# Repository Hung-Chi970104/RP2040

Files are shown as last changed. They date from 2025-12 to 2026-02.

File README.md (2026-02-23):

# RP2040 Hacker Board
- Demo video (with radio nrf24l01): https://youtu.be/eCMlnlmFBuc
- Demo video (radio control nrf24l01): https://youtu.be/_LA9TkBpY54

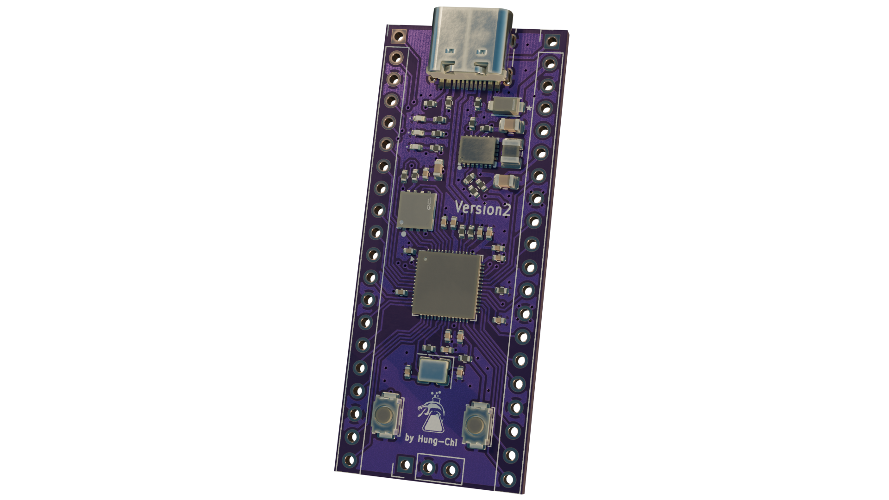
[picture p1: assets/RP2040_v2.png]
RP2040 V2


- Upgraded flash storage from 2MB (W25Q16JVUXIQ TR) to 16MB (W25Q64JVXGIQ)
- Replaced MCP1700x-330xxTT (linear regulator) with RT6154AGQW (buck-boost switching regulator)
- Added Schottky Diode to allow external power supply
- Added a RESET button
- Changed 33pF crystal cap to 15pF to match the crystal I ordered

## Components
- RP2040
- 12MHz Crystal (ABM8-272-T3)
- 8MB Flash Storage (W25Q64JVXGIQ)
- Buck-Boost Switching Regulator (RT6154AGQW)
- USB-C (TYPE-C-31-M-12)

## Pinouts
| Pin Number (Left) | Description | Pin Number (Right) | Description |
| --- | --- | --- | --- |
| 1 | GPIO0 | 1 | VBUS |
| 2 | GPIO1 | 2 | VSYS |
| 3 | GND | 3 | GND |
| 4 | GPIO2 | 4 | GPIO28_ADC2 |
| 5 | GPIO3 | 5 | GPIO27_ADC1 |
| 6 | GPIO4 | 6 | 3V3 |
| 7 | GPIO5 | 7 | GPIO26_ADC0 |
| 8 | BOOTSEL | 8 | GND |
| 9 | GPIO6 | 9 | GPIO25 |
| 10 | GPIO7 | 10 | GPIO24 |
| 11 | GPIO8 | 11 | GPIO23 |
| 12 | GPIO9 | 12 | GPIO22 |
| 13 | GND | 13 | GND |
| 14 | GPIO10 | 14 | GPIO21 |
| 15 | GPIO11 | 15 | GPIO20 |
| 16 | GPIO12 | 16 | GPIO19 |
| 17 | GPIO13 | 17 | GND |
| 18 | GND | 18 | GPIO18 |
| 19 | GPIO14 | 19 | GPIO17 |
| 20 | GPIO15 | 20 | GPIO16 |

## PCBs

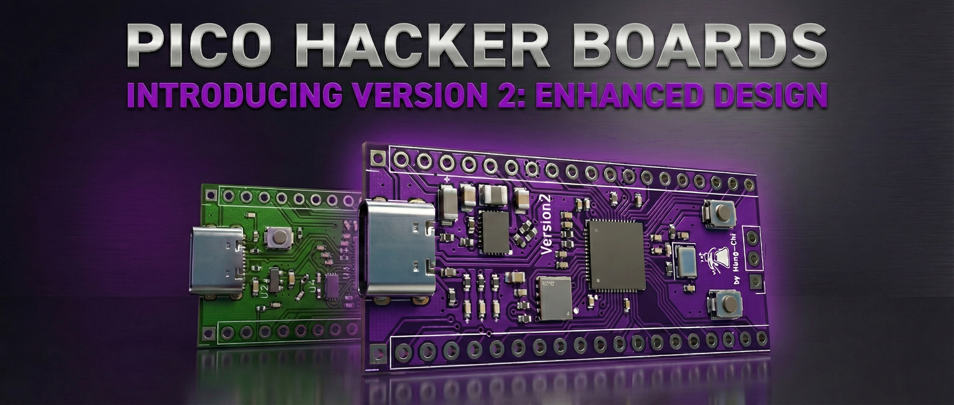
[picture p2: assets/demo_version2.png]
comparison


- 2 layers
- Single-sided component placement
- 2.6mm board thickness
- HASL (with lead) surface finish
- 1oz outer copper weight

### PCB Schematic
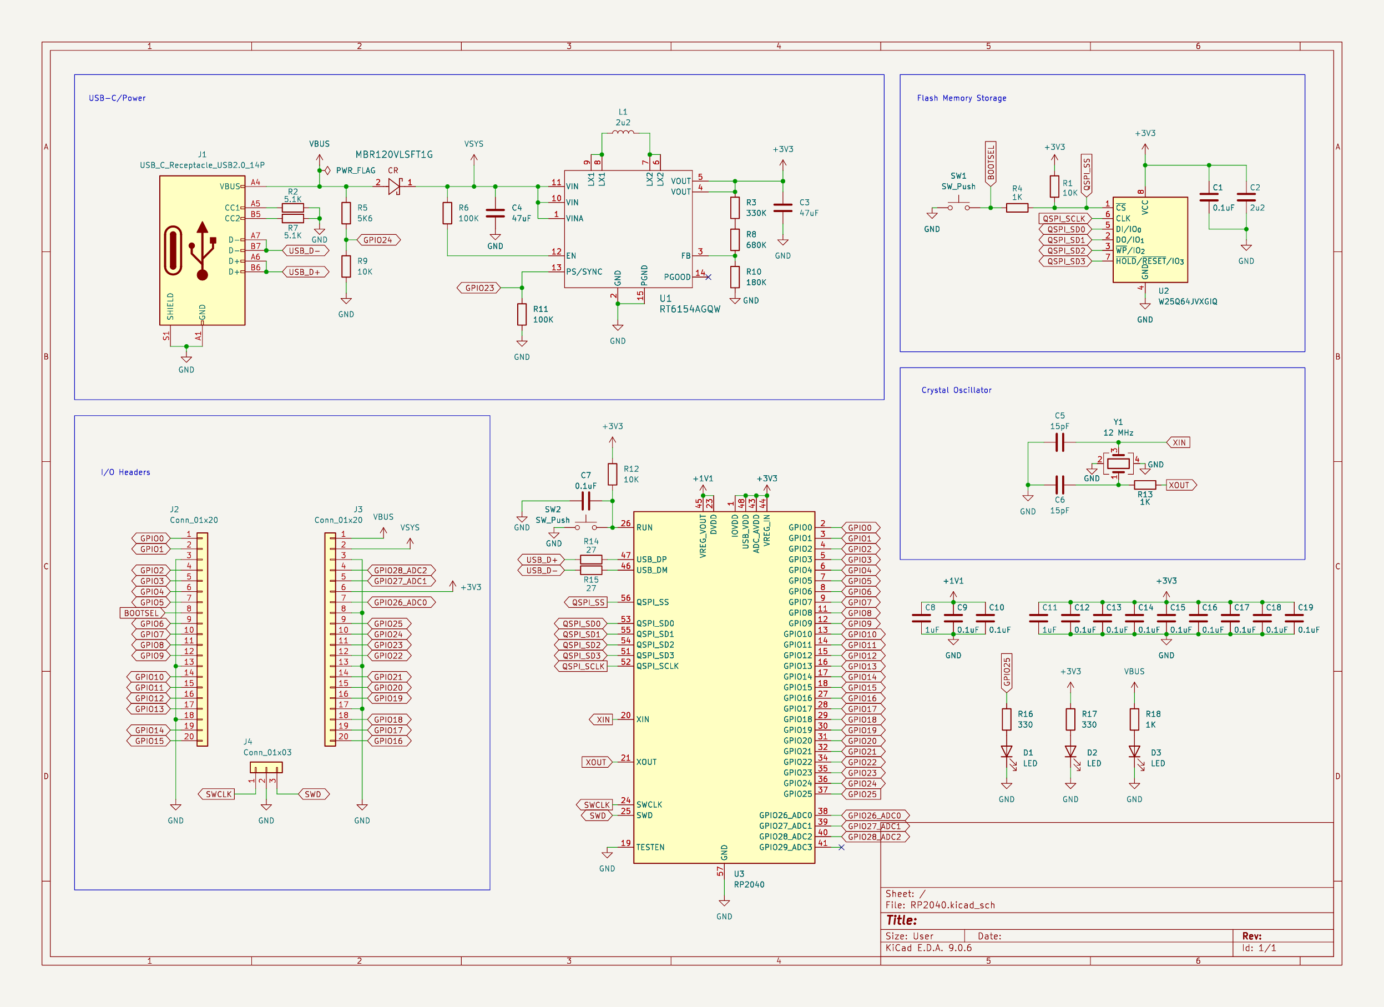
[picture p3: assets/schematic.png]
schematic


### PCB Layouts
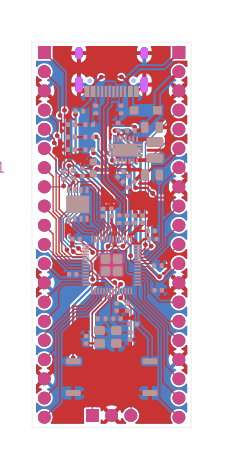
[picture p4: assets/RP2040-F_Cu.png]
pcb_layout_front

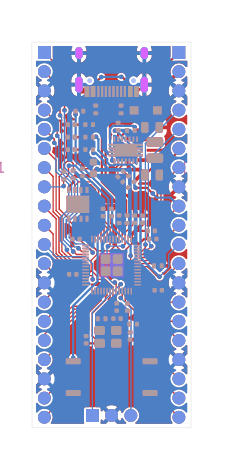
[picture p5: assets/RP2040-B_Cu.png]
pcb_layout_back


### 3D Model
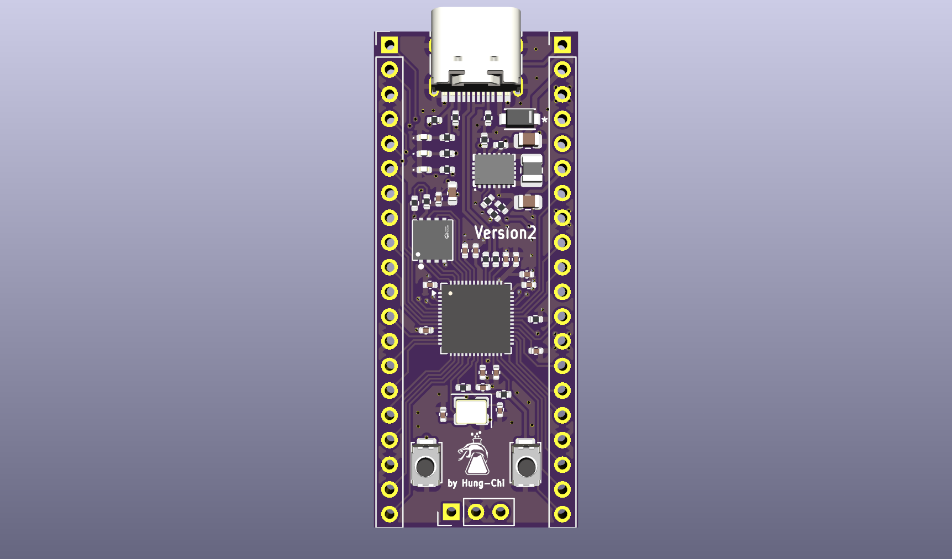
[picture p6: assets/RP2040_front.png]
model_front

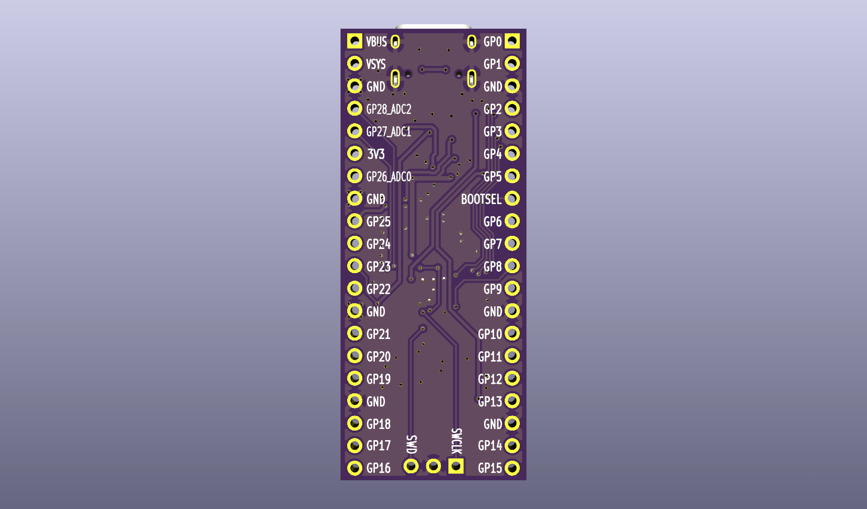
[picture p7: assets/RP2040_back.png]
model_back


## Rendered Demo
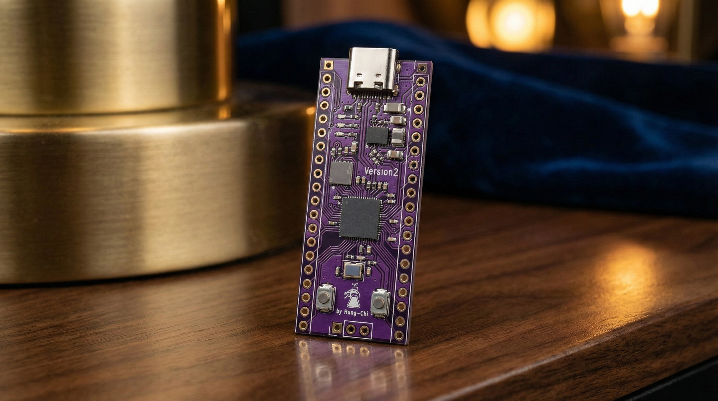
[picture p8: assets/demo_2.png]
demo_2

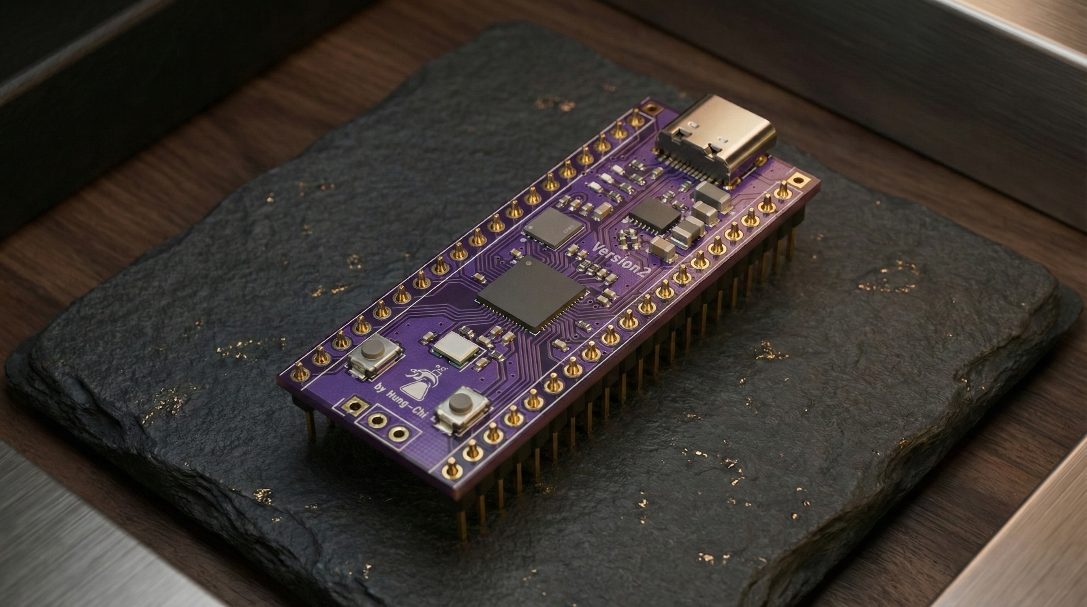
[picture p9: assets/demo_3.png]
demo_3

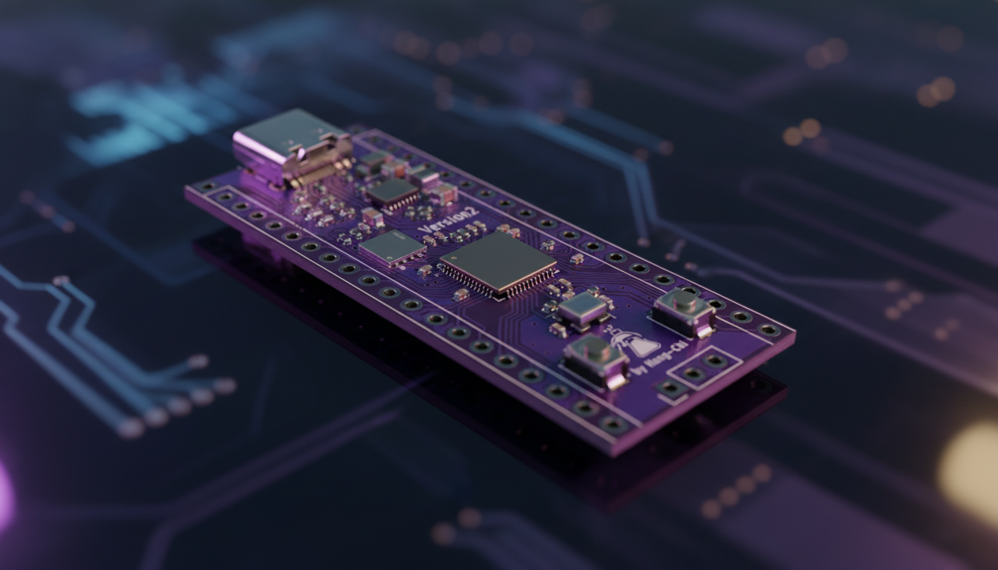
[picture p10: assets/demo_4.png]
demo_4


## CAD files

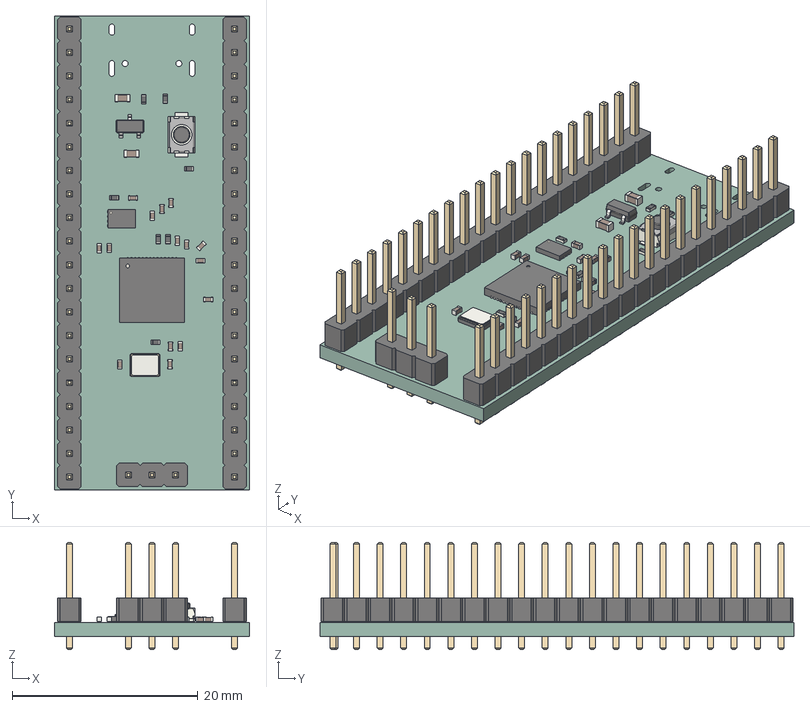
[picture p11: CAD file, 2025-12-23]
RP2040.step
21.0 x 51.0 x 11.5 mm
C_0402_1005Metric x 15
SOT-23
C_0603_1608Metric x 2
R_0402_1005Metric x 7
PinHeader_1x20_P2.54mm_Vertical x 2
SW_Push_SPST_NO_Alps_SKRK
QFN-56-1EP_7x7mm_P0.4mm_EP3.2x3.2mm
PinHeader_1x03_P2.54mm_Vertical
Winbond_USON-8-1EP_3x2mm_P0.5mm_EP0.2x1.6mm
Crystal_SMD_3225-4Pin_3.2x2.5mm
RP2040_PCB

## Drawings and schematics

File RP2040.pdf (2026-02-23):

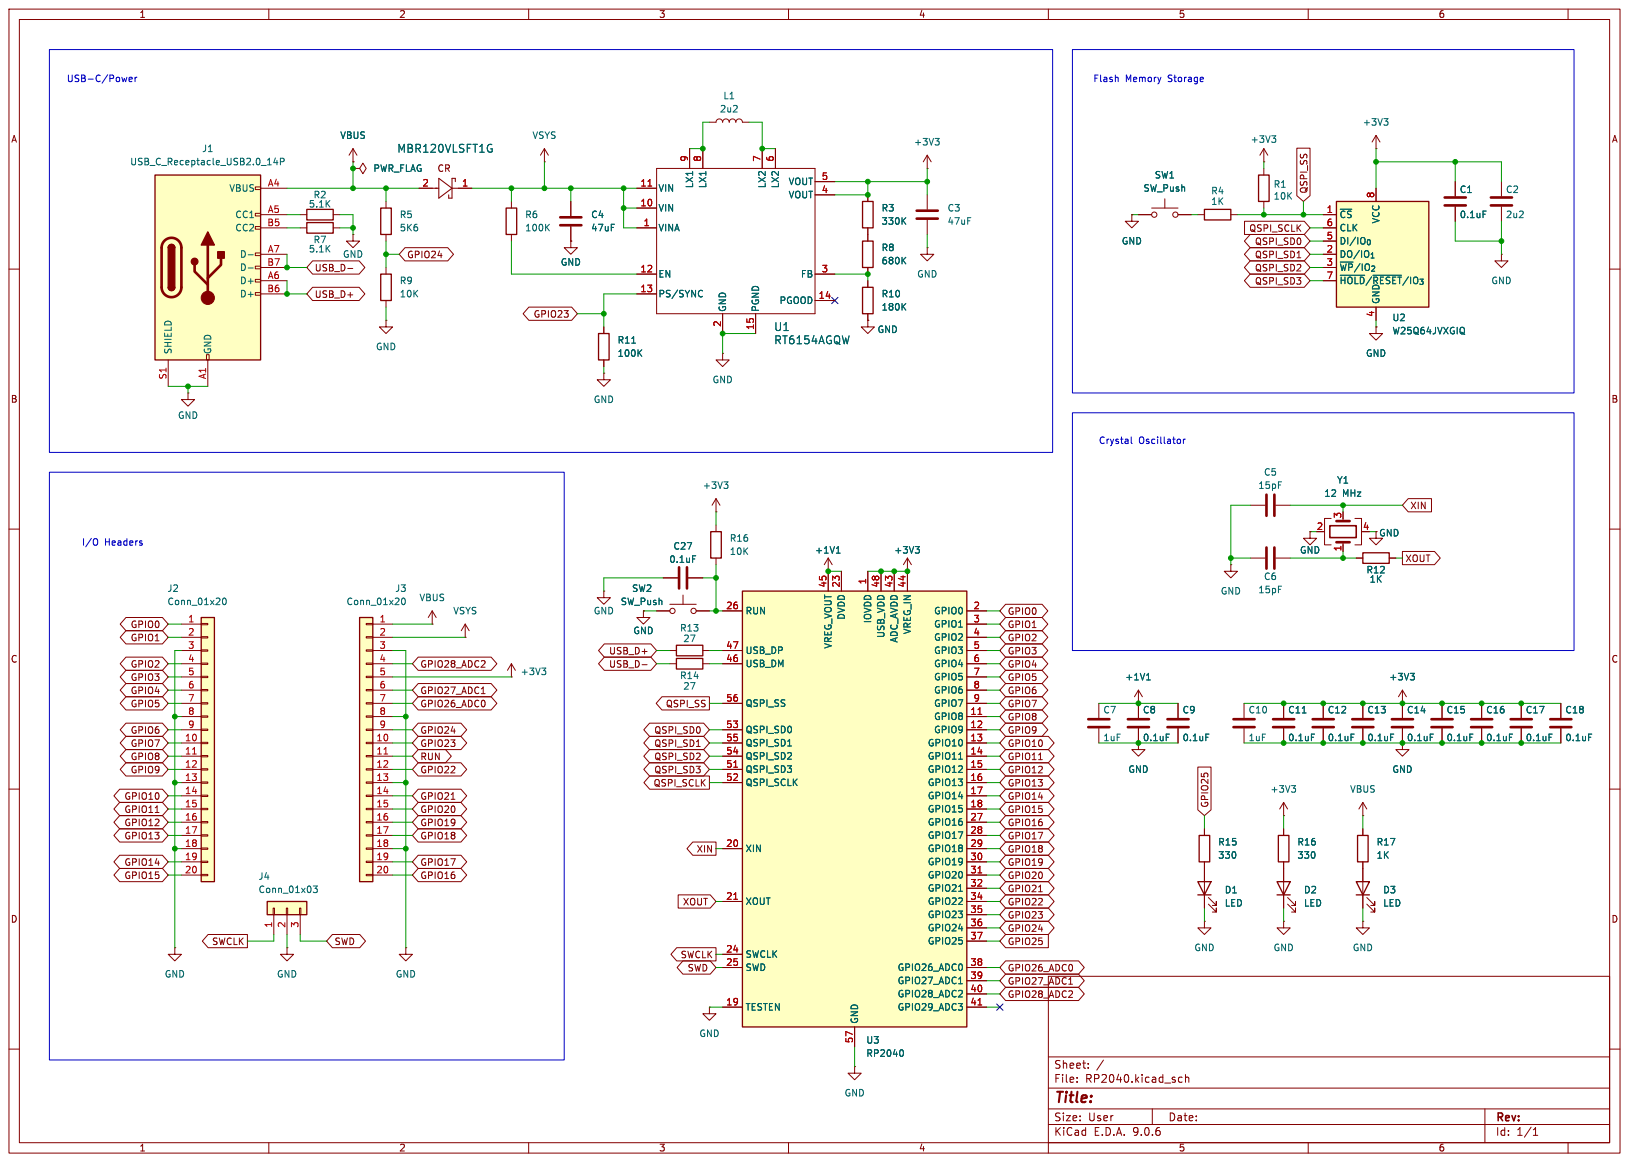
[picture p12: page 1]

6 VOUT 5 VOUT 4 FB 3 PGOOD 14 PWR_FLAG

6 VOUT 5 VOUT 4 FB 3 PGOOD 14 U1 RT6154AGQW

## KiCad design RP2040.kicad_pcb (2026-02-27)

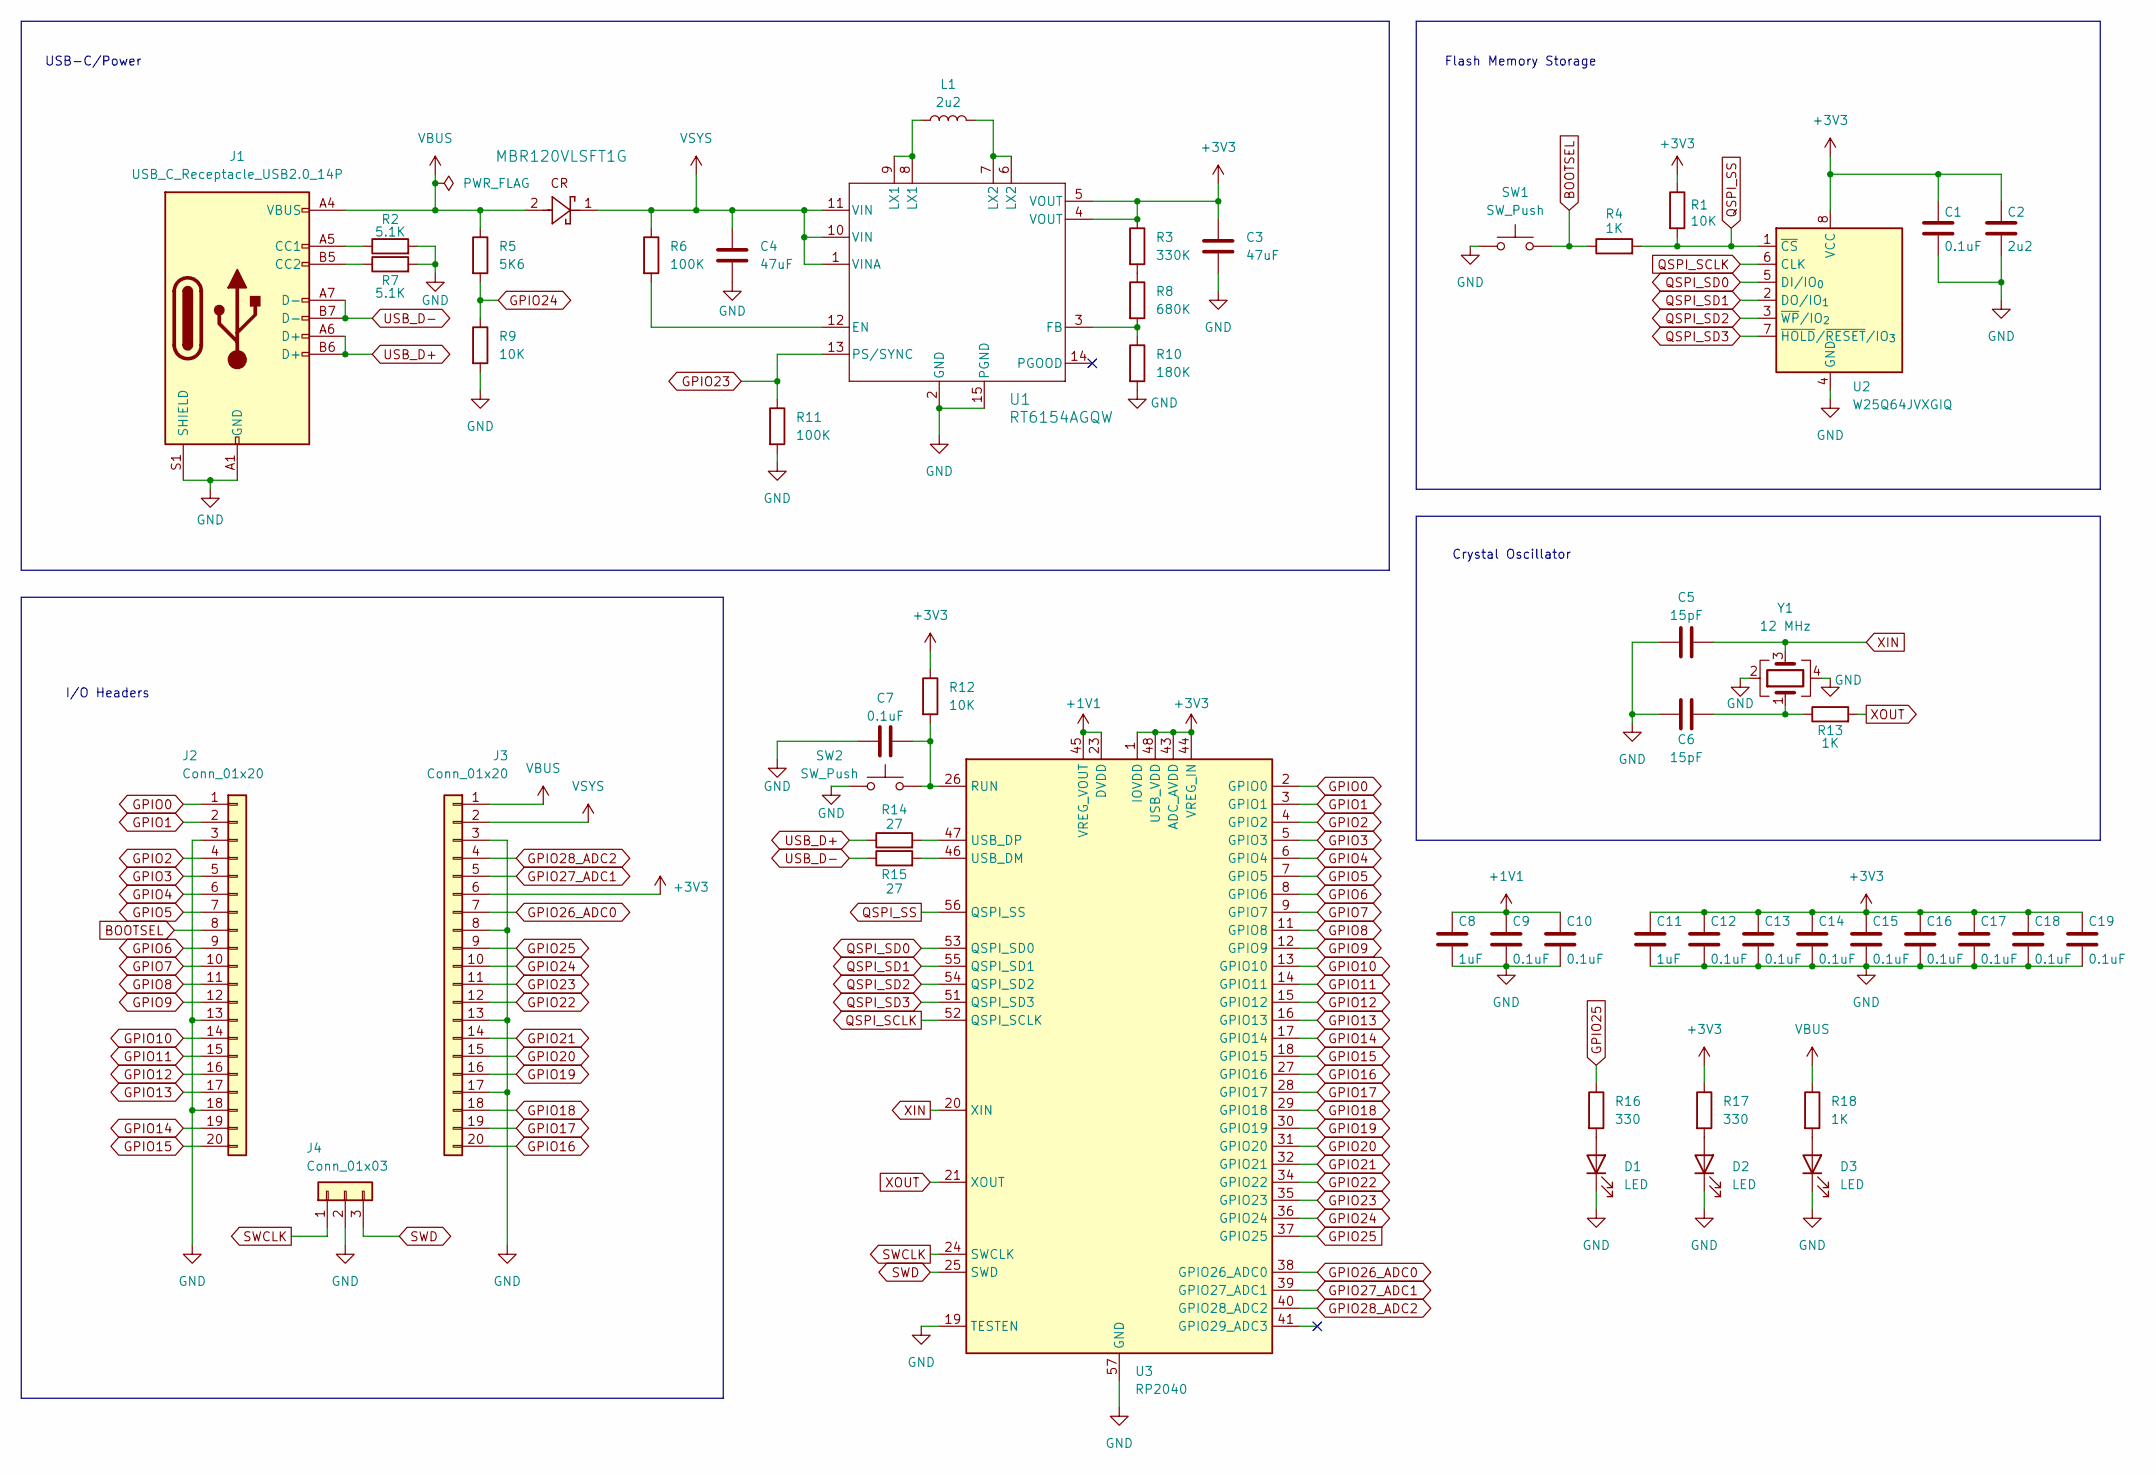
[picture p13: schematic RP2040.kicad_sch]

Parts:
111111111: MBR120VLSFT1G; SDO_SOD-123FL_ONS
C1, C7, C9, C10, C12, C13, C14, C15, C16, C17, C18, C19: 0.1uF; C_0402_1005Metric
C2: 2u2; C_0603_1608Metric
C3, C4: 47uF; C_0805_2012Metric
C5, C6: 15pF; C_0402_1005Metric
C8, C11: 1uF; C_0402_1005Metric
D1, D2, D3: LED; LED_0402_1005Metric
J1: USB_C_Receptacle_USB2.0_14P; USB_C_Receptacle_HRO_TYPE-C-31-M-12
J2, J3: Conn_01x20; PinHeader_1x20_P2.54mm_Vertical
J4: Conn_01x03; PinHeader_1x03_P2.54mm_Vertical
L1: 2u2; L_1008_2520Metric
R1, R9, R12: 10K; R_0402_1005Metric
R2, R7: 5.1K; R_0402_1005Metric
R3: 330K; R_0402_1005Metric
R4, R13, R18: 1K; R_0402_1005Metric
R5: 5K6; R_0402_1005Metric
R6, R11: 100K; R_0402_1005Metric
R8: 680K; R_0402_1005Metric
R10: 180K; R_0402_1005Metric
R14, R15: 27; R_0402_1005Metric
R16, R17: 330; R_0402_1005Metric
SW1, SW2: SW_Push; SW_Push_SPST_NO_Alps_SKRK
U1: RT6154AGQW; VSON-14_L4.0-W3.0-P0.50-BL-EP_TI_DSJ
U2: W25Q64JVXGIQ; XSON-8_L4.0-W4.0-P0.80-TL-EP
U3: RP2040; QFN-56-1EP_7x7mm_P0.4mm_EP3.2x3.2mm
Y1: 12 MHz; Crystal_SMD_3225-4Pin_3.2x2.5mm

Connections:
+1V1: C8.1, C9.1, C10.1, U3.23 (DVDD), U3.45 (VREG_VOUT), U3.50 (DVDD)
+3V3: C1.1, C2.1, C3.1, C11.1, C12.1, C13.1, C14.1, C15.1, C16.1, C17.1, C18.1, C19.1, J3.6, R1.1, R3.1, R12.1, R17.1, U1.4 (VOUT), U1.5 (VOUT), U2.8 (VCC), U3.1 (IOVDD), U3.10 (IOVDD), U3.22 (IOVDD), U3.33 (IOVDD), U3.42 (IOVDD), U3.43 (ADC_AVDD), U3.44 (VREG_IN), U3.48 (USB_VDD), U3.49 (IOVDD)
BOOTSEL: J2.8, R4.1, SW1.2
GND: C1.2, C2.2, C3.2, C4.2, C5.1, C6.1, C7.1, C8.2, C9.2, C10.2, C11.2, C12.2, C13.2, C14.2, C15.2, C16.2, C17.2, C18.2, C19.2, D1.1 (K), D2.1 (K), D3.1 (K), J1.A1 (GND), J1.A12 (GND), J1.B1 (GND), J1.B12 (GND), J1.S1 (SHIELD), J2.3, J2.13, J2.18, J3.3, J3.8, J3.13, J3.17, J4.2, R2.2, R7.2, R9.2, R10.2, R11.2, SW1.1, SW2.1, U1.2 (GND), U1.15 (PGND), U2.4 (GND), U3.19 (TESTEN), U3.57 (GND), Y1.2, Y1.4
GPIO0: J2.1, U3.2 (GPIO0)
GPIO1: J2.2, U3.3 (GPIO1)
GPIO2: J2.4, U3.4 (GPIO2)
GPIO3: J2.5, U3.5 (GPIO3)
GPIO4: J2.6, U3.6 (GPIO4)
GPIO5: J2.7, U3.7 (GPIO5)
GPIO6: J2.9, U3.8 (GPIO6)
GPIO7: J2.10, U3.9 (GPIO7)
GPIO8: J2.11, U3.11 (GPIO8)
GPIO9: J2.12, U3.12 (GPIO9)
GPIO10: J2.14, U3.13 (GPIO10)
GPIO11: J2.15, U3.14 (GPIO11)
GPIO12: J2.16, U3.15 (GPIO12)
GPIO13: J2.17, U3.16 (GPIO13)
GPIO14: J2.19, U3.17 (GPIO14)
GPIO15: J2.20, U3.18 (GPIO15)
GPIO16: J3.20, U3.27 (GPIO16)
GPIO17: J3.19, U3.28 (GPIO17)
GPIO18: J3.18, U3.29 (GPIO18)
GPIO19: J3.16, U3.30 (GPIO19)
GPIO20: J3.15, U3.31 (GPIO20)
GPIO21: J3.14, U3.32 (GPIO21)
GPIO22: J3.12, U3.34 (GPIO22)
GPIO23: J3.11, R11.1, U1.13 (PS/SYNC), U3.35 (GPIO23)
GPIO24: J3.10, R5.2, R9.1, U3.36 (GPIO24)
GPIO25: J3.9, R16.1, U3.37 (GPIO25)
GPIO26_ADC0: J3.7, U3.38 (GPIO26_ADC0)
GPIO27_ADC1: J3.5, U3.39 (GPIO27_ADC1)
GPIO28_ADC2: J3.4, U3.40 (GPIO28_ADC2)
unnamed: C6.2, R13.1, Y1.1
unnamed: D1.2 (A), R16.2
unnamed: D2.2 (A), R17.2
unnamed: D3.2 (A), R18.2
unnamed: J1.A5 (CC1), R2.1
unnamed: J1.B5 (CC2), R7.1
unnamed: L1.1, U1.8 (LX1), U1.9 (LX1)
unnamed: L1.2, U1.6 (LX2), U1.7 (LX2)
unnamed: R3.2, R8.1
unnamed: R6.2, U1.12 (EN)
unnamed: R8.2, R10.1, U1.3 (FB)
unnamed: C7.2, R12.2, SW2.2, U3.26 (RUN)
unnamed: R15.2, U3.46 (USB_DM)
unnamed: R14.2, U3.47 (USB_DP)
QSPI_SCLK: U2.6 (CLK), U3.52 (QSPI_SCLK)
QSPI_SD0: U2.5 (DI/IO_{0}), U3.53 (QSPI_SD0)
QSPI_SD1: U2.2 (DO/IO_{1}), U3.55 (QSPI_SD1)
QSPI_SD2: U2.3 (~WP/IO_{2}), U3.54 (QSPI_SD2)
QSPI_SD3: U2.7 (~HOLD/~RESET/IO_{3}), U3.51 (QSPI_SD3)
QSPI_SS: R1.2, R4.2, U2.1 (~CS), U3.56 (QSPI_SS)
SWCLK: J4.1, U3.24 (SWCLK)
SWD: J4.3, U3.25 (SWD)
USB_D+: J1.A6 (D+), J1.B6 (D+), R14.1
USB_D-: J1.A7 (D-), J1.B7 (D-), R15.1
VBUS: 111111111.2, J1.A4 (VBUS), J1.A9 (VBUS), J1.B4 (VBUS), J1.B9 (VBUS), J3.1, R5.1, R18.1
VSYS: 111111111.1, C4.1, J3.2, R6.1, U1.1 (VINA), U1.10 (VIN), U1.11 (VIN)
XIN: C5.2, U3.20 (XIN), Y1.3
XOUT: R13.2, U3.21 (XOUT)

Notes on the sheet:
Crystal Oscillator
I/O Headers
Flash Memory Storage
USB-C/Power

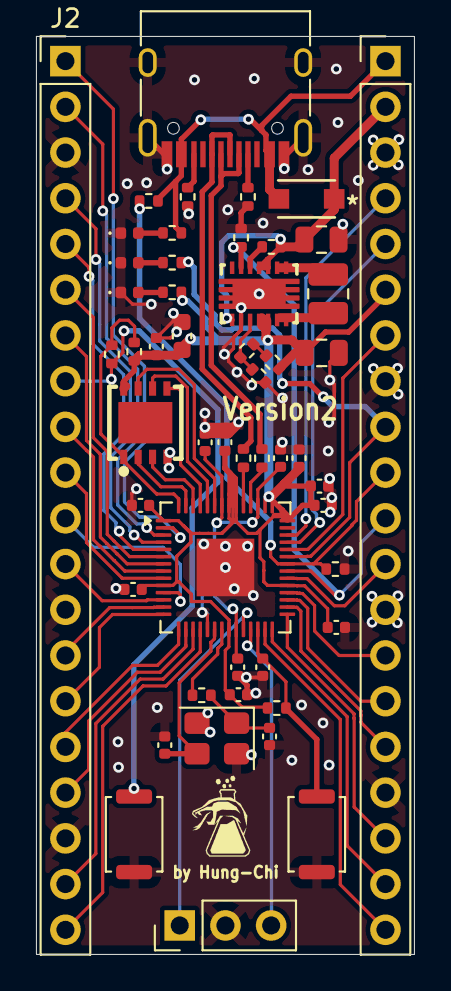
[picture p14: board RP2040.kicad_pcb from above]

Board: 2 copper layers, 21.0 x 51.0 mm, 51 parts (0 on the bottom side), 61 nets.

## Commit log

2025-12-23 Completed PCB Design
    [RP2040.kicad_pcb]
2025-12-23 Added 3D models
    [RP2040.3mf, RP2040.step]
2025-12-27 Update Schematic and PCB
    [RP2040.kicad_pcb, RP2040.kicad_sch]
2026-01-09 Cleaned up silkscreen labeles
    [RP2040.kicad_pcb]
2026-02-23 Update Readme + Images
    [RP2040.3mf, RP2040.kicad_pcb, RP2040.kicad_sch]
2026-02-27 update image
    [RP2040.kicad_pcb]
